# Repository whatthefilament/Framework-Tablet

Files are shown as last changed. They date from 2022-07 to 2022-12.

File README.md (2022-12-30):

# Framework-Tablet
3D Printable Tablet Case for Framework Laptop

The ethos for this project being is to make as few changes as possible to convert a Framework Laptop to a tablet form factor. In this case, I've used as many OEM Framework parts as possible.

The whole thing is held together with M3 fasteners and heat set inserts.

## Assembly

[Build Instructions](https://www.instructables.com/Framework-Tablet-Assembly-Manual/)

To help organize parts for this project, you can also print my free [Framework parts tray](https://www.printables.com/model/253099-framework-parts-tray)

For assembly, you will need the following:

- 25 - M3 heat inserts (short)
- 8 - M3 x 4mm screws
- 7 - M3 x 8mm screws
- 6 - M3 x 16mm screws
- 4 - M3 x 5mm screws

This tablet case is based on a 12.3-inch display [external display](https://www.amazon.com/gp/product/B08P1M54G6/?tag=whatthefilame-20)

To connect the display to the Motherboard, you will need a USB C 3.1. The cable must be able to provide power, data, and input. I used the following: [USB C Cable](https://www.amazon.com/dp/B09PTYKV6N?tag=whatthefilame-20&th=1)

## Print Settings:

I recommend printing all case parts of either ASA or ABS as this provides the best heat resistance.

This case is designed to be printed at 0.2mm layer height with a 0.4mm nozzle.

No printed supports are needed. All holes have built-in supports. STLs are properly oriented for correct printing.

The case is 317.2mm x 224mm x 24.6mm, so you will need a printer that can accommodate that size. I printed mine on a Voron 2.4 350mm

#

In addition to the Tablet case, you will find a wall dock and desktop dock to use in desktop mode or attached to an external monitor.

I've uploaded the step files for the model as well, so you can modify the frame to accept any screen you'd like.

I look forward to everyone's feedback. 

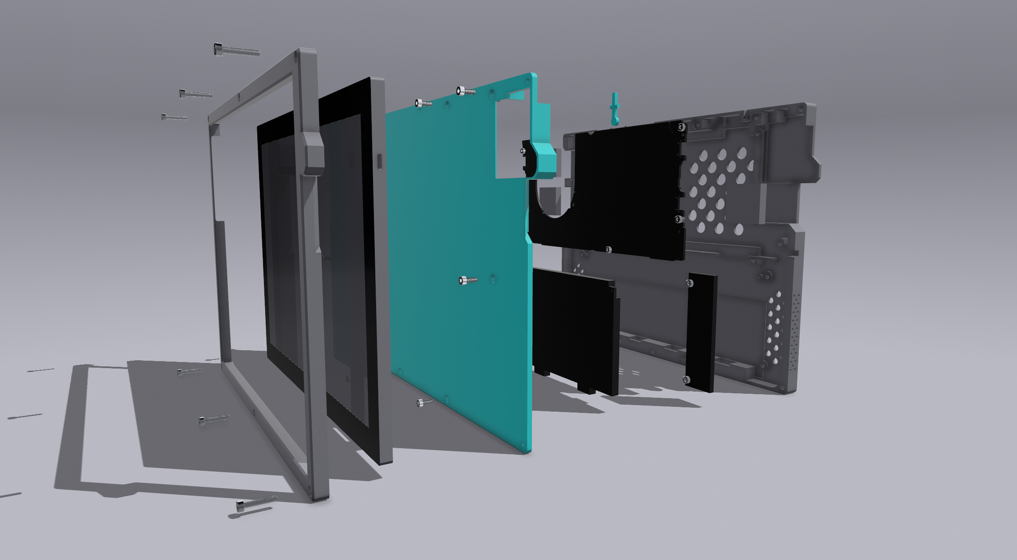
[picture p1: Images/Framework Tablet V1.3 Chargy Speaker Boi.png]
Tablet

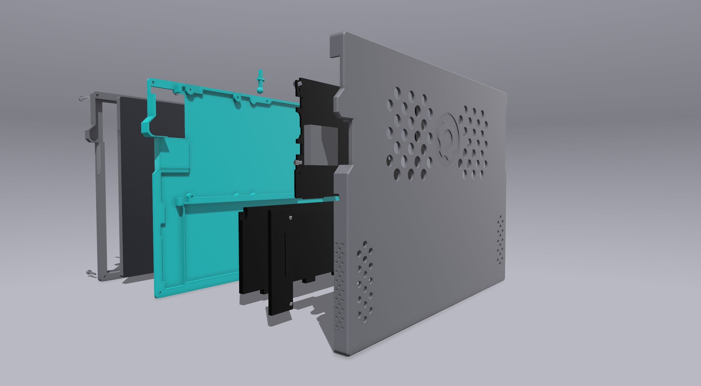
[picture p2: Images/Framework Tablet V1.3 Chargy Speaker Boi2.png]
Tablet2

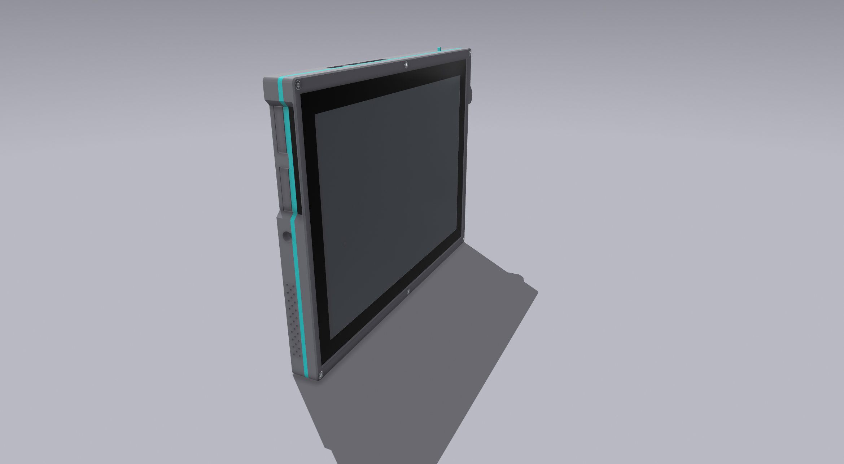
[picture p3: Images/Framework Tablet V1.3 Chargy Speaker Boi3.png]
Tablet3

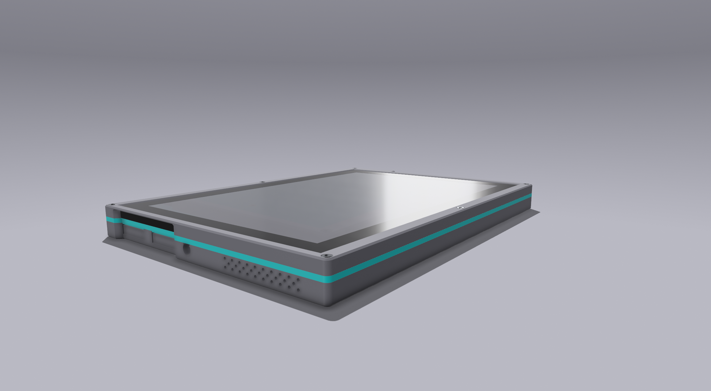
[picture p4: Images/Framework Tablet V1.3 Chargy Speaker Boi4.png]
Tablet4

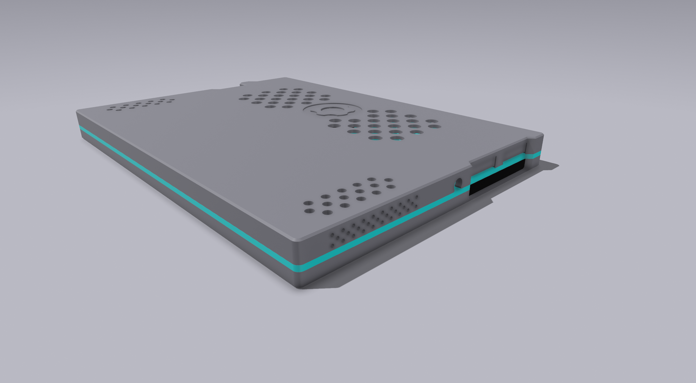
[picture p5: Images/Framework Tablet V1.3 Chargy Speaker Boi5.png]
Tablet5


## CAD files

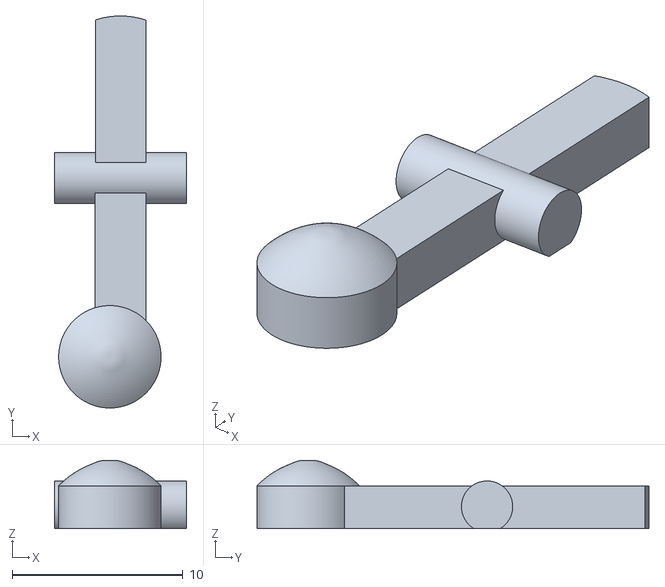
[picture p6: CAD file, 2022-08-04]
STLs/Switch.stl
7.75 x 23.0 x 4.01

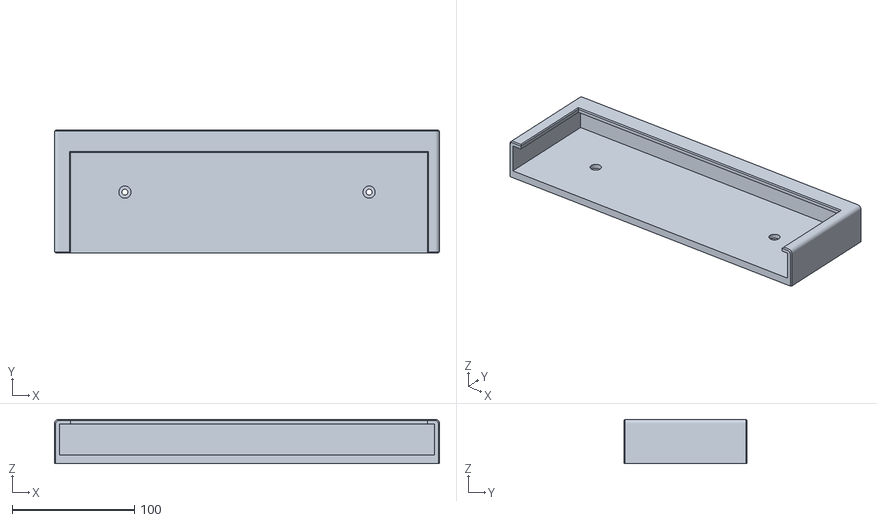
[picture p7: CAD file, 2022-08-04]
STLs/Wall Dock.stl
315.3 x 101.0 x 36.4

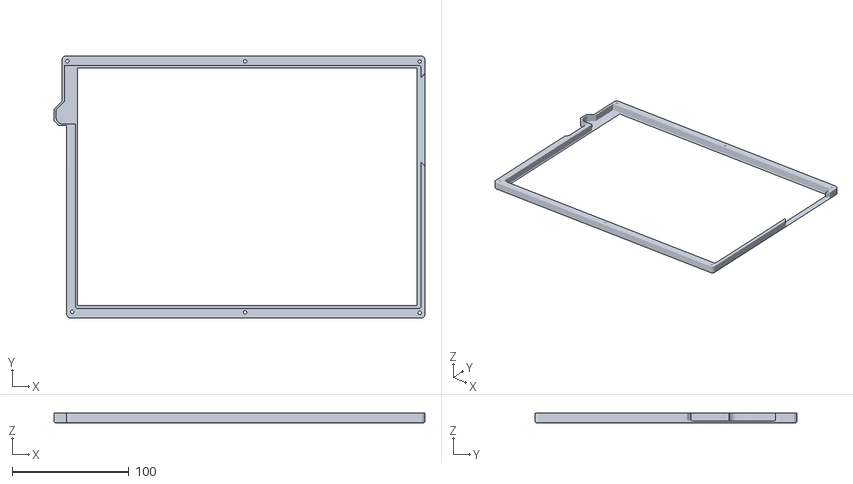
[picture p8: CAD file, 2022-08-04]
STLs/Bezel.stl
317.2 x 224.0 x 8.70

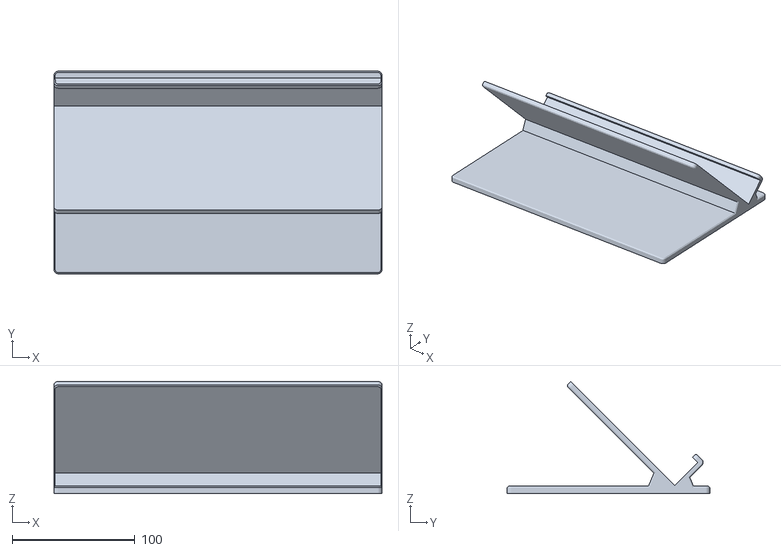
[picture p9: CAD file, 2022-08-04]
STLs/Desk Dock.stl
267.0 x 165.0 x 91.2

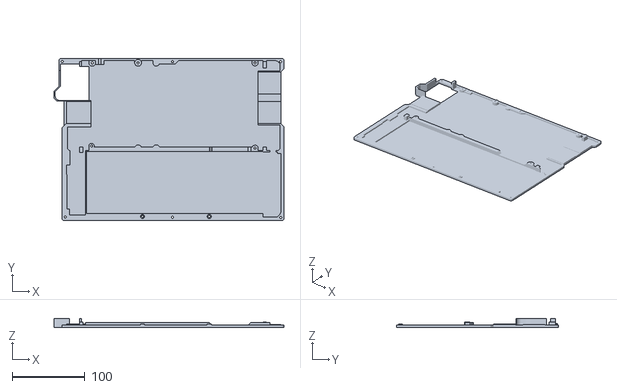
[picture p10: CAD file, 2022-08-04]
STLs/Middle Case.stl
317.2 x 224.1 x 12.3

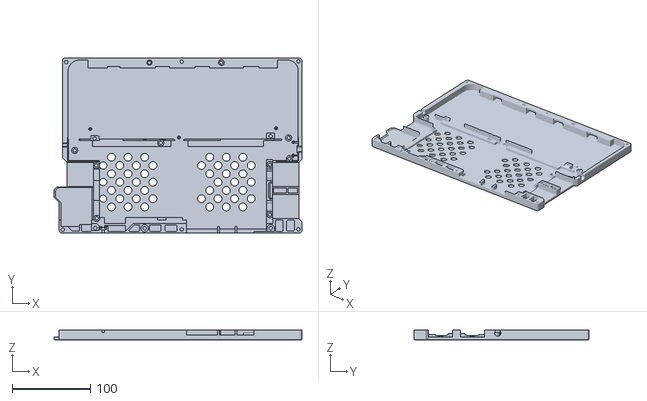
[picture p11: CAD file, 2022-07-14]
STLs/Back Case.stl
317.2 x 224.1 x 12.5

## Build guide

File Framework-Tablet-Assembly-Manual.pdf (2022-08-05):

instructables

Framework Tablet Assembly Manual (http://www.instructables.com/Framework-Tablet-Assembly-Manual/)

by whatthefilament (http://www.instructables.com/member/whatthefilament/)

Framework-Tablet
This assembly guide is intended to walk through how to assemble the 3D Printable Tablet Case for Framework Laptop. The ethos for this project being is to make as few changes as possible to convert a Framework Laptop to a tablet form factor. In this case, I've used as many OEM Framework parts as possible.
The whole thing is held together with M3 fasteners and heat set inserts.

Supplies:
Files for printing can be found on the project GitHub: https://github.com/whatthe+lament/Framework-Tablet (https://github.com/whatthefilament/Framework-Tablet)
To help organize parts for this project, you can also print my free Framework parts tray: https://www.printables.com/model/253099-framework-parts-tray
For assembly, you will need the following:
25 - M3 heat inserts (short) 8 - M3 x 4mm screws
7 - M3 x 8mm screws
6 - M3 x 16mm screws
4 - M3 x 5mm screws

This tablet case is based on a 12.3-inch display (https://www.amazon.com/gp/product/B08P1M54G6/ref=ox_sc_saved_title_4?smid=AA3SELAX5GFYF&psc=1)
To connect the display to the Motherboard, you will need a USB C 3.1. The cable must be able to provide power, data, and input. I used the following:
USB C Cable - https://www.amazon.com/dp/B09PTYKV6N?psc=1&ref=ppx_yo2ov_dt_b_product_details

Framework Tablet Assembly Manual: Page 1

Step 1: Print Parts
Step 2: Back Case Heat Set Inserts

Print Settings:
I recommend printing all case parts of either ASA or ABS as this provides the best heat resistance. This case is designed to be printed at 0.2mm layer height with a 0.4mm nozzle.
No printed supports are needed. All holes have built-in supports. STLs are properly oriented for correct printing.

The case is 317.2mm x 224mm x 24.6mm, so you will need a printer that can accommodate that size. I printed mine on a Voron 2.4 350mm.

In the picture above, you can see the highlighted location of the 25 M3 heat-set inserts in RED Please note the following:

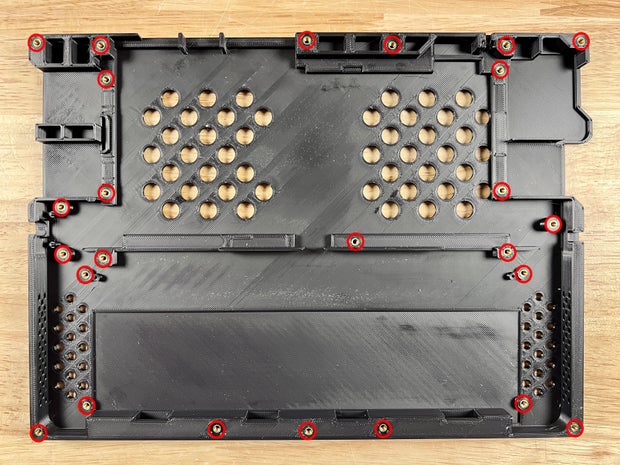
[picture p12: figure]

Step 3: Wifi Antenna Installation

This case needs short heat-set inserts. The ones I use have a length of 4mm. Any longer, and they will stick out too far.
The four heat set inserts used for the speakers that are highlighted in yellow have minimal plastic clearance below them, so be careful not to push too far. The plastic melts quickly and can deform the back of the case.
A soldering iron temperature of 250C is recommended if the part is printed in ASA or ABS.

To install a wi+ antenna in the tablet, you will need to remove the antenna from the OEM antenna bracket. This can be done by pealing the adhesive carefully and slowly.
Do not pull the cables out of the bracket before pealing the antennas from the OEM bracket. The wires are held onto each pad with a very small contact patch and can VERY EASILY be ripped oI from the antenna pads. The bracket helps hold them in place while pealing the antenna pads from the bracket. Once the antennas are pealed from the OEM bracket, you can then cut the bracket to remove the cables easily.

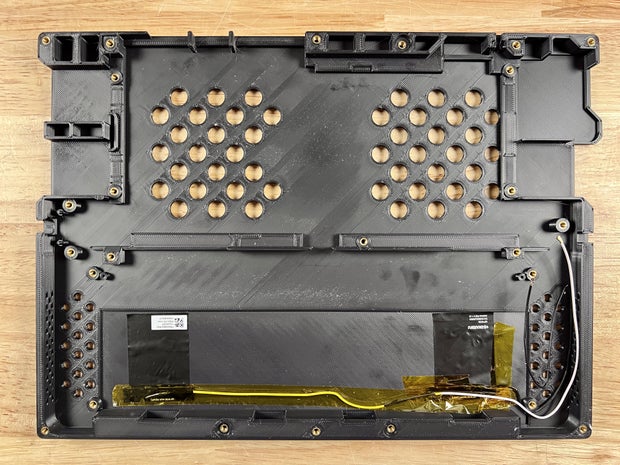
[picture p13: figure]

Step 4: Mainboard Installation

After the antennas have been removed from the OEM bracket, they can be placed in the back case, as seen in the picture above.
Use the pictures as a reference for routing the wi+ antenna wires
Each antenna pad has adhesive on the back that can be used to place them and hold them in place. I recommend using either Kapton tape or electrical tape to secure them a bit more and protect them from rubbing against the battery.

The mainboard can now be placed in the case as shown in the picture above. The board is held in place by 5 M3 x 4mm screws as highlighted in RED. Make sure your RAM and SSD are installed at this stage as well.

TIP: While not necessary, it is highly recommended to compress the case detection switch with Kapton tape. You can see this highlighted in YELLOW in the picture above. While you can use any tape to compress the switch, it is recommended to use Kapton as the adhesive will not break down due to the heat produced by the mainboard. If you do not compress this switch, the board will Kash red whenever it is turned on.

Step 5: Wifi and Audio Board Installation

The audio board is mounted on the left of the mainboard, as highlighted in RED; it is secured with 2 M3 x 4mm screws. Do not forget to plug in the audio board cable to both the audio board and mainboard at this step.

The wi+ board is mounted on the right of the mainboard, as highlighted in YELLOW; it is secured with a single M3 x 4mm screw.
Attach both the black and white antenna cables to the appropriate terminals at this step . This is labeled on the board with a white and black triangle next to each terminal.
You may also have some spare cable that can be folded and will be tucked behind the speakers in the next step.

Step 6: Speaker Installation

Each speaker is held in place with 2 M3 x 5mm screws. (4 in total) The speakers have markings for left and right, which coincide with the side of the case they are installed on.
If you do not see these markings, the speaker with the short wire is installed on the left.
Do not overtighten the screws, as the speakers have rubber grommets that allow them to be isolated from the rest of the chassis.

Once secured in the case, connect the speaker wire to the mainboard as highlighted in RED in the picture above.

Step 7: Battery Installation

The battery sits in the bottom case exactly as it does in the Framework laptop. You will slide the bottom tabs into the retaining slots on the bottom of the case and secure using the stock screws that are pre-installed in the battery. They will cut their own threads into the plastic.
Do not forget to plug the battery into the mainboard at this step as well.
Please note: Only the two outer screws are used to hold the battery in place. The center screw is not used.

Step 8: Power Switch

The power switch is placed in a small cutout on the top right of the back case. Please make sure to install the switch with the Kat side facing up.
The round ball on the end of the switch is intended to contact the power switch on the mainboard.

Please note: The switch is held in place with the case divider. The switch can easily fall out if the case is Kipped or moved before the case divider is installed.

Step 9: Expansion Cards

At this point, you will want to install your three expansion cards of choice.

Step 10: Display Cable

You will now want to connect the Kexible USB C cable to the top right expansion port.

Step 11: Case Divider

With all components installed into the back case, you can install the case divider to protect the internal components from the touch display.
The divider is held in place with 7 M3 x 8mm screws highlighted in RED. Ensure when installing the divider that you route the USB C cable through the hole in the divider.

Step 12: Display

Connect the display to the tablet using the USB C cable

Step 13: First Boot

I recommend you boot the tablet at this point using the switch before installing the top case. Booting at this step will allow you to ensure everything is working correctly, making it easier to dissemble if something needs to be +xed.
You may also need to unplug and replug the display to get the board to recognize it on the +rst boot.

Please note that the display output may be 'ipped on the (rst boot. If it is needed in the Windows setting menu under display settings, you can rotate the output to display in your preferred orientation.
You may also want to make the touch keyboard available in the taskbar, as this will make it easier to locate the keyboard if it does not load on its own when you are attempting to type

Step 14: Top Case

Once all operations above are completed and you have con+rmed all functions are working, you can install the top case/display retainer.
The top case is held in place with 6 M3 x 16mm screws.
The USB C cable is Kexible and can be folded on top of itself and pushed inside the case opening to align the top case properly.

Step 15: Assembly Complete!

Congratulations! You now have a functional Framework Tablet!
I hope you enjoyed this build. Be sure to let me know if you have any recommendations for improvements to the build.

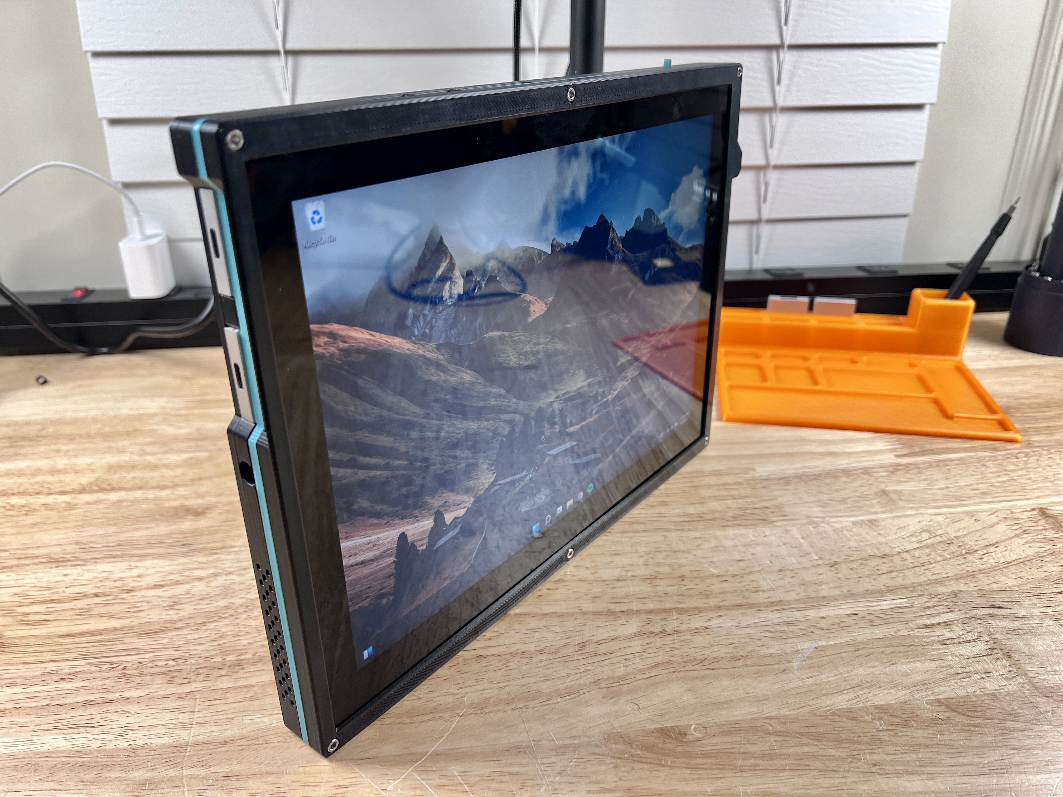
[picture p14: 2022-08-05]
Images/Assembly Instruction Manual Pictures/Originals/IMG_0046.JPG

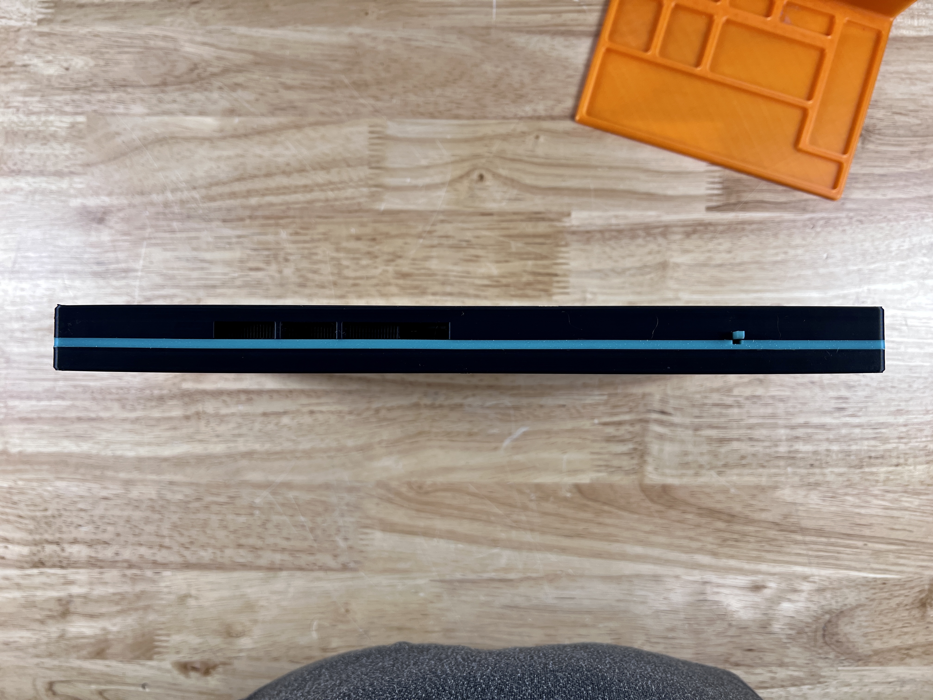
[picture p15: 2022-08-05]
Images/Assembly Instruction Manual Pictures/Originals/IMG_0051.JPG

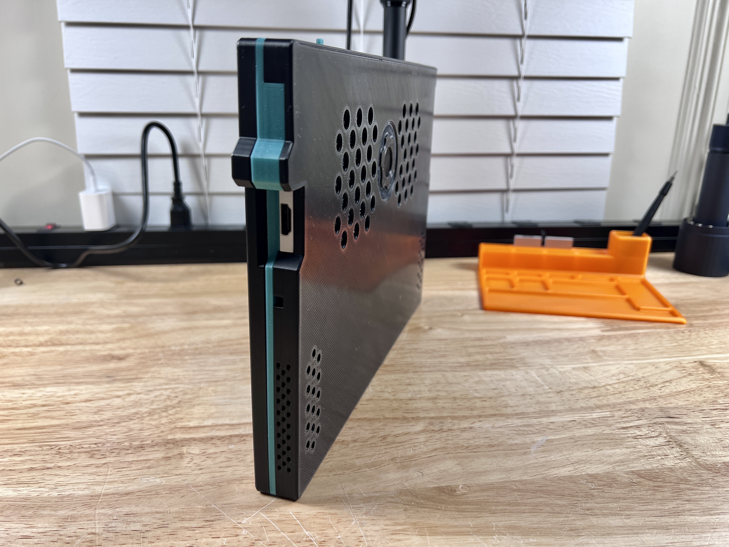
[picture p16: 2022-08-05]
Images/Assembly Instruction Manual Pictures/Originals/IMG_0049.JPG

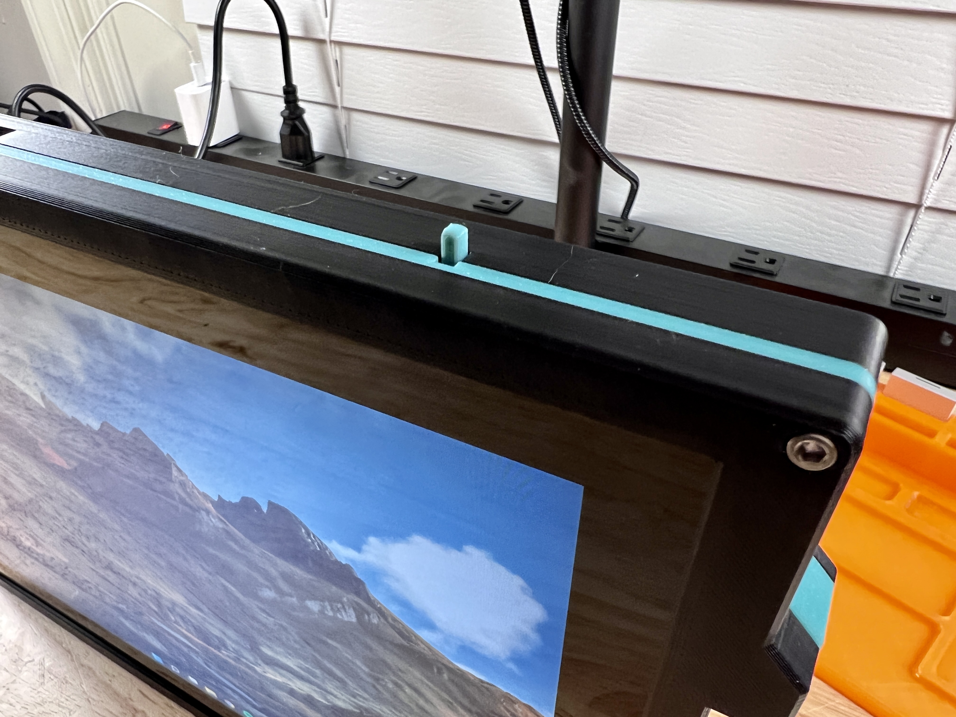
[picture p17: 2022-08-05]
Images/Assembly Instruction Manual Pictures/Originals/IMG_0052.JPG

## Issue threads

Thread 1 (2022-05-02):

High-quality stylus-compatible touchscreen with mainline Linux support

raj-magesh, 2022-05-02:
Hey, do you have any recs for an excellent touchscreen with stylus support (i.e. low input lag, pressure sensitivity, ergonomic, decent resolution) that also has Linux drivers in the mainline kernel?

Thanks for the cool project: really excited to see where it goes!

lrlucchini, 2022-05-02:
Are the ports for displays pretty standard? Could i in theory find a better screen on Amazon that works with the motherboard port?

whatthefilament, 2022-05-02:
@lrlucchini The motherboard has an EDP port that it uses for the factory monitor. If you can find a touchscreen monitor that uses an EDP port you could certainly find a better screen. To make it easier to obtain parts, i based this design around a stock external display you'd use with any computer. With the step files, you can modify the bezel to accept any monitor you'd like. I suggest finding one that does power, data, and touch-over USB to keep wiring simple.

Closed 2022-05-29.

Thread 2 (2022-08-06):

CC-BY-SA 4.0 licence for image files?

junaruga, 2022-08-06:
Hello,

Thanks for creating this amazing project!
I am an editor of the [Framework's Wikipedia page](https://en.wikipedia.org/wiki/Framework_Computer). And I want to upload [this photo file](https://github.com/whatthefilament/Framework-Tablet/blob/main/Images/Assembly%20Instruction%20Manual%20Pictures/Originals/IMG_0046.JPG) on this repository, to the Wikipedia page as a case of an individually driven project.

I can upload it by myself via [Upload Wizard](https://commons.wikimedia.org/wiki/Special:UploadWizard). However, it seems that Wikipedia (the wizard) only allows the licenses below in the following screenshot. And the "CC-BY-SA 4.0" is the default.

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

So I have a suggestion. Could you adjust the license info of this repository for image files to have the CC-BY-SA 4.0 license or other CC licenses on the list?

Here are some projects of doing this for your reference.

* https://source.mnt.re/reform/pocket-reform/-/blob/main/README.md
  > Other documentation, artwork, photos and drawings that are not trademarks (see below): [CC-BY-SA 4.0](https://creativecommons.org/licenses/by-sa/4.0/legalcode)
* https://github.com/penk/MainboardTerminal/blob/master/README.md#copyright-and-license
* https://github.com/brickbots/framedeck/blob/main/README.md#copyright-and-license

Thanks!

whatthefilament, 2022-08-06:
Hey @junaruga, I don't think they let you adjust the license for a repository after you make the initial commit.

I am happy to send an email permitting as outlined in the screenshot of the wizard.

whatthefilament, 2022-08-06:
@junaruga are there any specific files you want to use? It looks like  I can go into the wizard and upload them myself and grant permission

whatthefilament, 2022-08-06:
Picture 1:

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
https://commons.wikimedia.org/wiki/File:Framework_Tablet_Overview.jpg

Picture 2:

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
https://commons.wikimedia.org/wiki/File:Framework_Tablet_Internals.jpg

Picture 3:

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
https://commons.wikimedia.org/wiki/File:Framework_Tablet_Complete_Build.jpg

Picture 4:

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
https://commons.wikimedia.org/wiki/File:Framework_Tablet_Complete_Build_Back.jpg

junaruga, 2022-08-06:
Thanks for your help! Yeah, I wanted to see the Picture 3 (`Originals/IMG_0046.JPG`) to be uploaded.

junaruga, 2022-08-06:
I added your photo to the page: https://en.wikipedia.org/wiki/Framework_Computer now!

By the way, I just want to share one tip that might be a tip for an uploaded photo to be kept, not to be deleted on Wikipedia. In the past, I saw a person upload his artwork (wallpaper) image to Wikimedia. Then after days or months, it was deleted by Wikipedia. I don't know why.

When I upload a 3rd person's photo, I added the Summary - Source item as the original photo URL just in case. So far all the photos I uploaded by myself are not deleted on Wikipedia.
E.g. https://commons.wikimedia.org/wiki/File:Mainboard-terminal-heroshot.jpg

whatthefilament, 2022-08-06:
Awesome! Thanks for the highlight!

junaruga, 2022-08-07:
Yeah, possibly the current photo is okay. In the past, I uploaded my Framework Laptop photos as own work without the Summary - Source item and the link. And those are still kept there :)

* https://commons.wikimedia.org/wiki/File:Framework_laptop_part_made_with_love_by_team.jpg
* https://commons.wikimedia.org/wiki/File:Framework_laptop_sway_community_forum_small.png

whatthefilament, 2022-08-07:
Just looking at your posts. Jealous your able to get a fair phone. Wish they sold them in the US

junaruga, 2022-08-07:
Yeah, I am using Fairphone 3, and I am happy with it. The metadata in the first link shows the info. It was easy to buy it as I live in the Czech Republic. :)

Closed 2022-08-06.

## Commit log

2022-06-17 v1.1 update
    [Framework Tablet_Back Case.stl, Framework Tablet_Bezel.stl, Framework Tablet_Middle Case.stl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]
2022-07-14 v1.2 thick boi
    Thick boi update. Improves fitment and fixes switch position and accuracy.
    [Back Case.stl, Bezel.stl, Framework Tablet v1.2 Thick Boi.step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]
2022-07-14 STL Orientation
    Oriented STL's for proper printing
    [Back Case.stl, Bezel.stl, Middle Case.stl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]
2022-07-14 small change to wifi mount
    [Back Case.stl, Bezel.stl, Framework Tablet v1.2 Thick Boi.step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]
2022-07-15 Tablet Dock
    [Dock.step, Dock.stl]
2022-07-18 Wall Dock
    Added wall dock
    [Desktop Dock.step, Desktop Dock.stl, Wall Dock.step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]
2022-08-04 V1.3
    Chargy Speaker Boi update
    [Bezel.stl, Desk Dock.stl, Desktop Dock.step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]
